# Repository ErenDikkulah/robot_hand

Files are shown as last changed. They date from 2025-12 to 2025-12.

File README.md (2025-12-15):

# 3-Finger Dexterous Robot Hand

**Project:** ENRO — Robotics R&D  
**Assigned to:** Eren  
**Reviewed by:** Emre / Team Lead  
**Date:** 09.12.2025

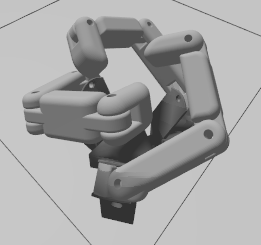
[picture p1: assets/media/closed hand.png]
Closed hand


A 3-finger robot hand model written and simulated using Ros2 Jazzy and Gazebo Harmonic

[report page](assets/docs/three_finger_hand_report.md) ● [media folder](assets/media) ● [older assignment file](Assignment.md) ● [related Fusion files](parts) ● [required stl files](src/three_finger_hand/meshes)

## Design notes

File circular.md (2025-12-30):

# 🤖 Circular IK Trajectory Assignment — Robot Hand / Arm

## 🎯 Goal
Make the robot hand/arm trace a **smooth circular path** in 3D space using **inverse kinematics**, execute it in simulation, and verify the resulting motion both numerically and visually.

---

## ✅ Learning & System Objectives
- Generate a 3D circular trajectory mathematically
- Apply inverse kinematics continuously along a path
- Ensure smooth joint-space motion without jumps
- Execute trajectory in simulation and verify correctness

---

## 🏗️ Phase 1 — Circle Definition in 3D (Task-Space Path)
Implement:
```
generate_circle_points(center, normal, radius, N)
```
### Requirements
- Circle should work in any plane (not just XY)
- Use orthonormal basis construction
- Keep orientation constant for now

### Deliverables
- `circle_generator.py`
- 3D plot of circle

---

## 🧮 Phase 2 — Circular IK Computation
For each waypoint:
- compute IK
- warm‑start solver with previous result
- handle failures gracefully

### Acceptance
- ≥ 95% successful IK
- No large joint jumps
- Joint limits respected

### Deliverables
- `circular_ik.py`
- joint trajectory plot

---

## ▶️ Phase 3 — Execute Motion
Execute using ROS2 / MuJoCo / Custom Controller

### Requirements
- smooth motion
- configurable duration
- repeat at least 3 loops

### Deliverables
- working motion
- short video / GIF

---

## 🔎 Phase 4 — Validation & Proof
Must show:
1️⃣ EE path is circular  
2️⃣ Error acceptable

### Provide
- EE path plot
- RMSE tracking error
- Discussion on:
  - tracking
  - IK stability
  - workspace issues

---

## 📂 Submission Structure
```
circular_ik_assignment_<name>/
 ├─ src/
 │   ├─ circle_generator.py
 │   ├─ circular_ik.py
 │   └─ execution_script.py
 ├─ plots/
 │   ├─ circle_path.png
 │   ├─ joint_trajectories.png
 │   └─ ee_tracking_error.png
 ├─ video/
 │   └─ circular_motion.mp4
 └─ report.md
```

---

## 📄 report.md Must Include
- explanation of approach
- circle parameters
- solver description
- encountered problems
- evaluation

---

## ⭐ Bonus
- orientation follows tangent
- closed‑loop IK
- variable speed
- ellipse path

---

## 🕒 Suggested Timeline
| Phase | Time |
|---|---|
| Path Generation | 2h |
| IK Integration | 3–4h |
| Execution | 2h |
| Validation | 1–2h |

---

## ✅ Acceptance Checklist
- ☐ Circle correct
- ☐ IK continuous
- ☐ No joint blowups
- ☐ Stable execution
- ☐ Evidence provided

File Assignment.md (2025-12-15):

# ASSIGNMENT — 3-Finger Dexterous Robot Hand (Design + UI + Simulation)
**Project:** ENRO — Robotics R&D  
**Assigned to:** Eren  
**Reviewed by:** Emre / Team Lead  
**Date:** 09.12.2025

---

## 1. Objective
Develop a **3-finger dexterous robot hand**, inspired by the Shadow Robot x DeepMind hand:

https://shadowrobot.com/news/press-releases/shadow-robot-unveils-the-worlds-most-robust-dexterous-robot-hand-developed-in-partnership-with-google-deepmind/

Your tasks:

1. Use the provided Fusion 360 design files (or converted STEP/STL files).  
2. Assemble a **3‑finger hand**, with **120° finger spacing**.  
3. Create the **simulation-ready model** (URDF/Xacro).  
4. Build the **control UI**.  
5. Demonstrate the hand in simulation with joint movements and poses.

You do **not** need to redesign the parts—use the Fusion files provided.  
If conversion is needed, get help from the team.

---

## 2. Deliverables

### Mandatory
- 3D model assembled from provided Fusion files  
- `three_finger_hand.urdf.xacro`  
- Simulation launch files (RViz + Gazebo / Isaac Sim)  
- UI for joint control  
- Simulation demo video or screenshots  
- `docs/three_finger_hand_report.md`

### Optional
- Gesture presets (pinch, tripod, open/close cycle)  
- RViz panel plugin  
- Grasp animation  

---

## 3. Inputs You Will Receive
You will be given:

- Fusion 360 model files  
- A demonstration video  
- A reference image  

Convert formats (STEP/STL/OBJ) if required with help from the team.

---

## 4. Tasks (Step-by-Step)

### **Task 1 — Study the reference**
Understand the Shadow Robot hand’s:
- Dexterity  
- Joint structure  
- Grasp ability  

---

### **Task 2 — CAD Assembly**
- Import Fusion 360 files  
- Adjust axes & origin  
- Fix scaling and mesh orientation  
- Assemble 3 fingers at **120° spacing**  
- Export meshes as STL/OBJ

Output directory:

```
hand_description/meshes/
```

---

### **Task 3 — URDF / Xacro Model**
Define:
- All links  
- All joints  
- Joint limits  
- Visual + collision meshes

Use modular Xacro macros.

Final URDF path:

```
hand_description/urdf/three_finger_hand.urdf.xacro
```

---

### **Task 4 — Simulation Integration**
Create:

- `display.launch.py` (RViz)  
- `simulation.launch.py` (Gazebo/Isaac)

Simulation requirements:
- All joints work  
- No physics explosions  
- Stable poses  

---

### **Task 5 — UI**
Use PyQt5 or PySide2.

UI must include:
- Sliders for each joint  
- “Open Hand” button  
- “Close Hand” button  
- Pose buttons  
- Real-time joint feedback  

Publish to:

```
/three_finger_hand_controller/commands
```

---

### **Task 6 — Demo**
Show:
- All fingers closing  
- Two-finger pinch  
- Three-finger grasp  
- Open/close animation  

---

## 5. Acceptance Criteria

### CAD  
- Fusion files imported cleanly  
- 3-finger model accurate and aligned

### URDF/Xacro  
- No missing meshes  
- Joint orientations correct  
- Launch files working

### Simulation  
- Joints move smoothly  
- Stable behavior  
- Poses executed correctly

### UI  
- Sliders functional  
- Buttons functional  
- Commands published correctly

### Documentation  
- README with instructions  
- Explanation of joints and setup  

### Delivery  
- Branch name: `feature/three-finger-hand-eren`  

---

## 6. Notes for Eren
- Don’t waste time redrawing parts — use the provided Fusion files.  
- Convert formats only if needed.  
- Ask to the team for conversion help.  
- Work in this order: **CAD → URDF → Simulation → UI → Demo**.  
- Keep everything modular and clean.

---

**End of file.**

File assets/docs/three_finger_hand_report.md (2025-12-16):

# Report for assignment - 3-Finger Dexterous Robot Hand (Design + UI + Simulation)

**Author**: Eren

This project contains a 3-finger robot, its UI, simulation and design. This robot is developed with Ros2 Jazzy, simulated with Gazebo Harmonic, and has a UI made with Tkinter.

## Usage

After cloning project, and being sure installing required programs, go to the project directory and open 3 terminals. Then, run the code below.

```bash
# Terminal 1 (To view in RViz, optional)
source install/setup.bash
colcon build # 1-time-required, additionally required after editing
ros2 launch three_finger_hand display.launch.py # Opens config.rviz automatically

# Terminal 2 (To simulate in Gazebo)
source install/setup.bash
colcon build # Run if skipped Terminal 1
ros2 launch three_finger_hand simulation.launch.py

# Terminal 3 (To drive the robot using GUI)
python3 src/three_finger_hand/launch/controller_gui.py
```

## Data and media related to the robot

You can find related Fusion files in the ```parts``` folder, and STL files in the ```src/three_finger_hand/meshes``` directory. Also, the ```assets``` folder includes media related to robot. Here are some screenshots while robot running.

* Screenshot from robot in RViz

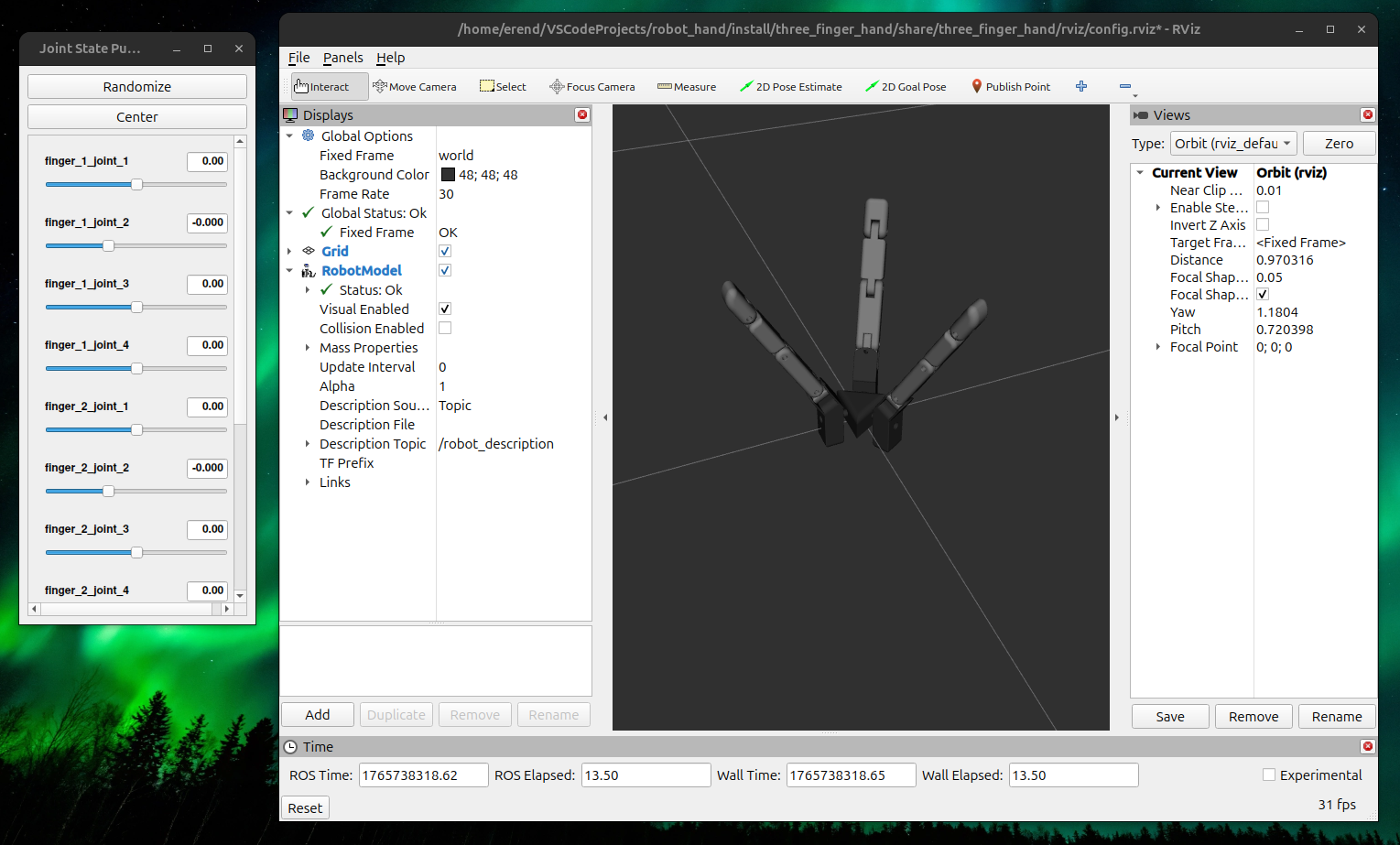
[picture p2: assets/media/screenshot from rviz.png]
Screenshot from RViz


* Screenshot from robot in Gazebo and GUI control tool

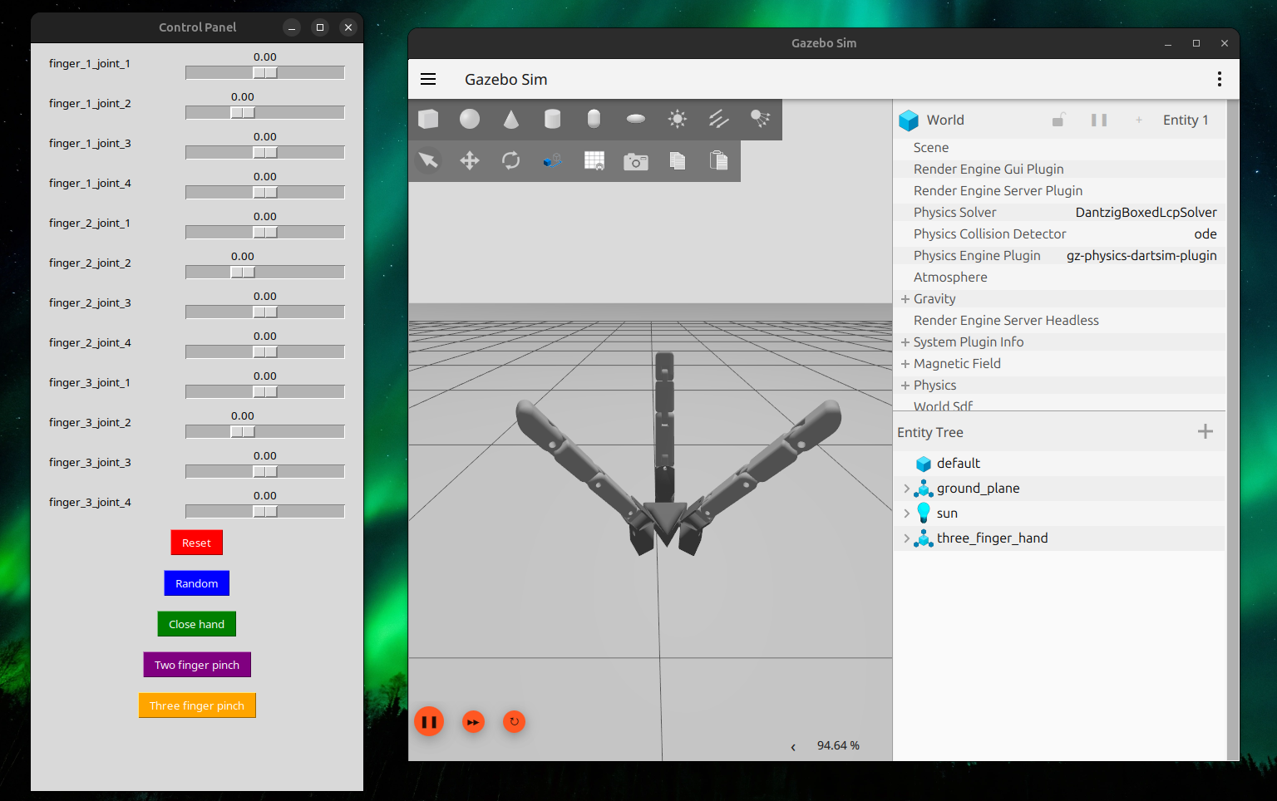
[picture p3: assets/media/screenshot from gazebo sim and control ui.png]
Screenshot from Gazebo


* Video from Gazebo Sim showing demo movements

Demo movement video

* Photo from the robot in Fusion

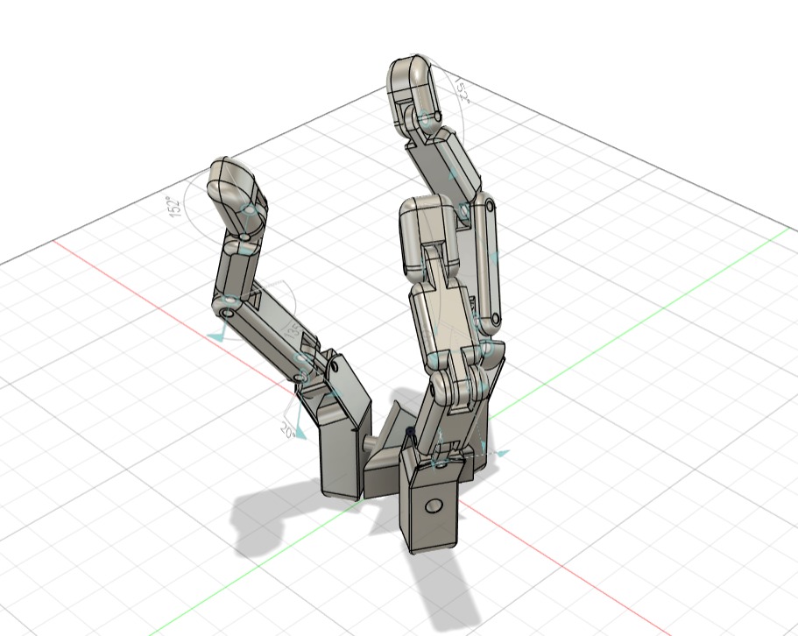
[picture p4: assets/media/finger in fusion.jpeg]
Photo from Fusion


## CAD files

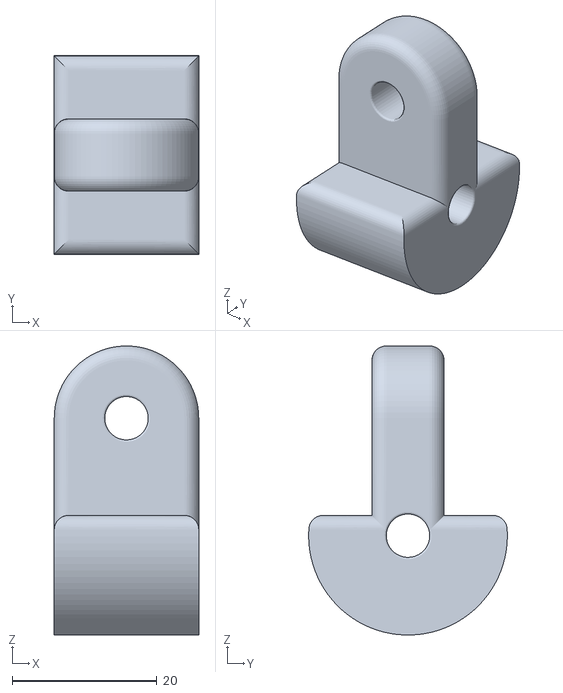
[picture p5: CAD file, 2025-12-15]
src/three_finger_hand/meshes/finger_knuckle.stl
20.0 x 27.5 x 40.0

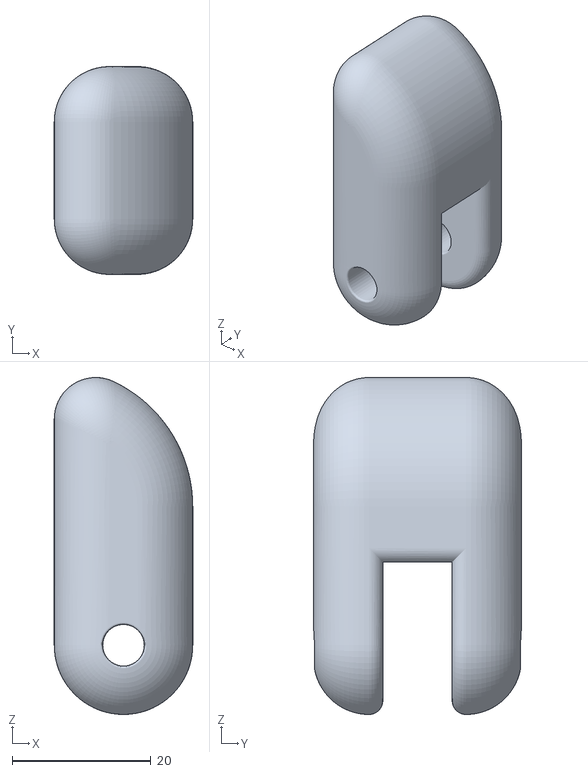
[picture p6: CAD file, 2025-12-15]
src/three_finger_hand/meshes/finger_distal.stl
20.0 x 30.0 x 48.6

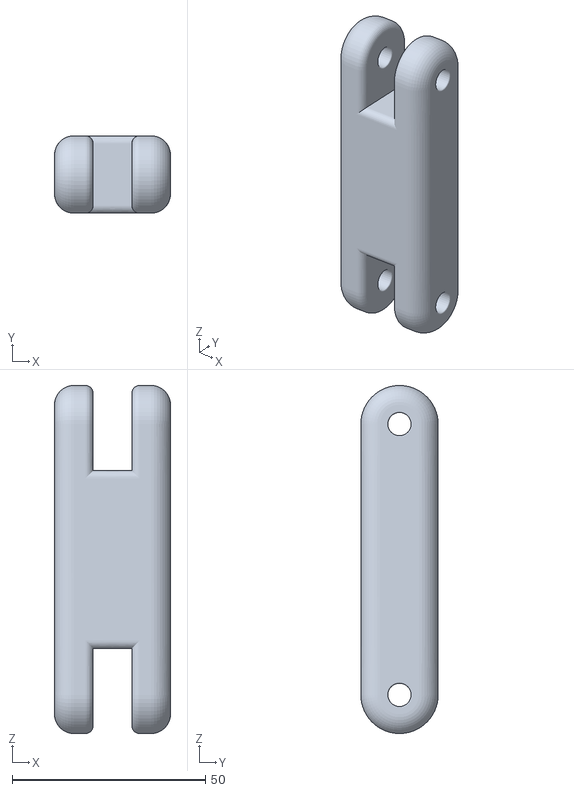
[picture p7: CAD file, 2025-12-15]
src/three_finger_hand/meshes/finger_proximal.stl
30.0 x 20.0 x 90.0

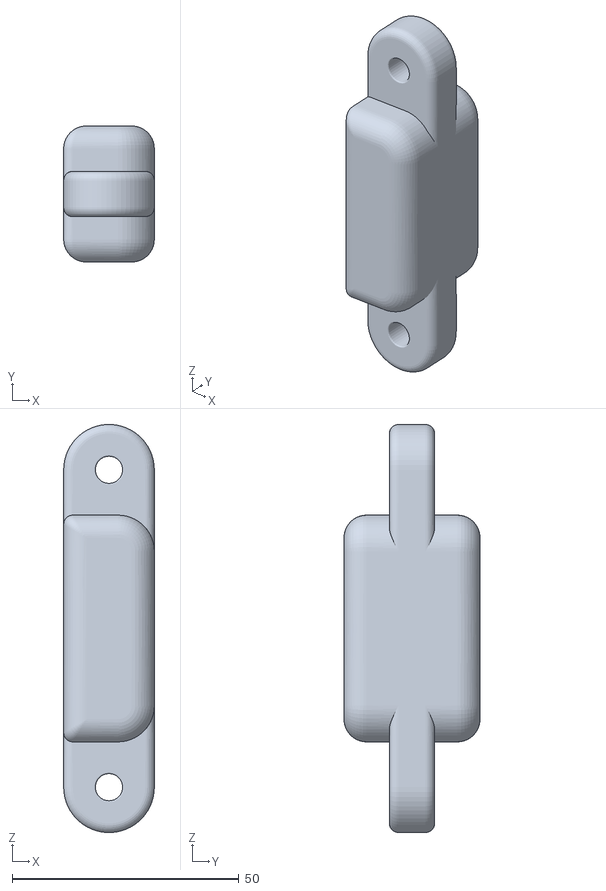
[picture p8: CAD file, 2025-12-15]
src/three_finger_hand/meshes/finger_middle.stl
20.0 x 30.0 x 90.0

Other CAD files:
parts/distal v1.f3d
parts/finger_montage v1.f3z
parts/hand_montage v0.f3z
parts/knuckle v1.f3d
parts/middle v1.f3d
parts/proximal v1.f3d
parts/wrist v1.f3d
parts/wrist_integrator.f3d

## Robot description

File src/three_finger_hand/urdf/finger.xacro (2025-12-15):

<?xml version="1.0"?>
<robot xmlns:xacro="http://www.ros.org/wiki/xacro">

  <xacro:macro name="finger" params="prefix parent *origin">

    <joint name="${prefix}_joint_1" type="revolute">
      <parent link="${parent}"/>
      <child link="${prefix}_knuckle"/>
      <xacro:insert_block name="origin"/>
      <axis xyz="1 0 0"/> <limit lower="-1.256" upper="1.256" effort="10" velocity="1.0"/>
      <damping value="0.5"/>
      <dynamics friction="0.5"/>
    </joint>

    <link name="${prefix}_knuckle">
      <visual>
        <origin xyz="0 0 0" rpy="0 0 0"/>
        <geometry>
          <mesh filename="package://three_finger_hand/meshes/finger_knuckle.stl" scale="0.001 0.001 0.001"/>
        </geometry>
        <material name="grey">
          <color rgba="0.5 0.5 0.5 1.0"/>
        </material>
      </visual>
      <collision>
        <origin xyz="0 0 0" rpy="0 0 0"/>
        <geometry>
          <mesh filename="package://three_finger_hand/meshes/finger_knuckle.stl" scale="0.001 0.001 0.001"/>
        </geometry>
      </collision>
      <inertial>
        <mass value="0.03"/>
        <inertia ixx="0.005" ixy="0" ixz="0" iyy="0.005" iyz="0" izz="0.005"/>
      </inertial>
    </link>

    <joint name="${prefix}_joint_2" type="revolute">
      <parent link="${prefix}_knuckle"/>
      <child link="${prefix}_proximal"/>
      <origin xyz="0 0 0.01025" rpy="0 0 1.57"/> 
      <axis xyz="1 0 0"/> <limit lower="-0.628" upper="1.256" effort="10" velocity="1.0"/>
      <damping value="0.5"/>
      <dynamics friction="0.5"/>
    </joint>

    <link name="${prefix}_proximal">
      <visual>
        <origin xyz="0 0 0" rpy="0 0 0"/>
        <geometry>
          <mesh filename="package://three_finger_hand/meshes/finger_proximal.stl" scale="0.001 0.001 0.001"/>
        </geometry>
        <material name="grey"/>
      </visual>
      <collision>
        <origin xyz="0 0 0" rpy="0 0 0"/>
        <geometry>
           <mesh filename="package://three_finger_hand/meshes/finger_proximal.stl" scale="0.001 0.001 0.001"/>
        </geometry>
      </collision>
      <inertial>
        <mass value="0.05"/>
        <inertia ixx="0.005" ixy="0" ixz="0" iyy="0.005" iyz="0" izz="0.005"/>
      </inertial>
    </link>

    <joint name="${prefix}_joint_3" type="revolute">
      <parent link="${prefix}_proximal"/>
      <child link="${prefix}_middle"/>
      <origin xyz="0 0 0.07" rpy="0 0 -1.57"/>
      <axis xyz="0 1 0"/>
      <limit lower="-1.256" upper="1.256" effort="10" velocity="1.0"/>
      <damping value="0.5"/>
      <dynamics friction="0.5"/>
    </joint>

    <link name="${prefix}_middle">
      <visual>
        <origin xyz="0 0 0" rpy="0 0 0"/>
        <geometry>
          <mesh filename="package://three_finger_hand/meshes/finger_middle.stl" scale="0.001 0.001 0.001"/>
        </geometry>
        <material name="grey"/>
      </visual>
      <collision>
        <origin xyz="0 0 0" rpy="0 0 0"/>
        <geometry>
          <mesh filename="package://three_finger_hand/meshes/finger_middle.stl" scale="0.001 0.001 0.001"/>
        </geometry>
      </collision>
      <inertial>
        <mass value="0.04"/>
        <inertia ixx="0.005" ixy="0" ixz="0" iyy="0.005" iyz="0" izz="0.005"/>
      </inertial>
    </link>

    <joint name="${prefix}_joint_4" type="revolute">
      <parent link="${prefix}_middle"/>
      <child link="${prefix}_distal"/>
      <origin xyz="0 0 0.07" rpy="0 0 0"/>
      <axis xyz="0 1 0"/>
      <limit lower="-1.57" upper="1.57" effort="10" velocity="1.0"/>
      <damping value="0.5"/>
      <dynamics friction="0.5"/>
    </joint>

    <link name="${prefix}_distal">
      <visual>
        <origin xyz="0 0 0" rpy="0 0 0"/>
        <geometry>
          <mesh filename="package://three_finger_hand/meshes/finger_distal.stl" scale="0.001 0.001 0.001"/>
        </geometry>
        <material name="grey"/>
      </visual>
      <collision>
        <origin xyz="0 0 0" rpy="0 0 0"/>
        <geometry>
          <mesh filename="package://three_finger_hand/meshes/finger_distal.stl" scale="0.001 0.001 0.001"/>
        </geometry>
      </collision>
      <inertial>
        <mass value="0.02"/>
        <inertia ixx="0.005" ixy="0" ixz="0" iyy="0.005" iyz="0" izz="0.005"/>
      </inertial>
    </link>

  </xacro:macro>
</robot>

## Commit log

2025-12-11 add ros2 package, create rviz sim file, rename required folders, add xacro files, add gitignore
    [finger.xacro, finger_distal.stl, finger_knuckle.stl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]
2025-12-14 fix lenght values
    [finger.xacro]
2025-12-14 add gui controller file, edit joint limits to solve mechanical problems
    [finger.xacro, three_finger_hand.urdf.xacro]
2025-12-14 add randomize button to gui
